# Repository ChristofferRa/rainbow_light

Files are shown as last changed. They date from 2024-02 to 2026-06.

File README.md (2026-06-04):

# Rainbow Lamp project

This is the code for my Wifi-connected rainbow-lamp project.  
The hardware is based on an ESP32-C3 super mini and a WS2812B-led strip in a custom designed 3d-printed enclosure in the form of a Rainbow and clouds.  
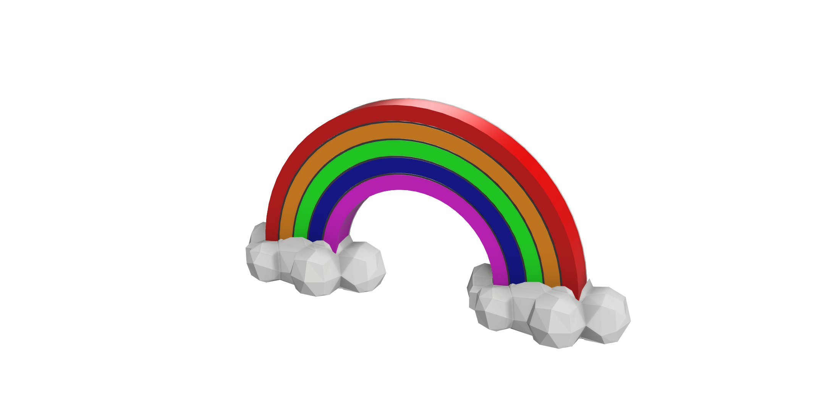
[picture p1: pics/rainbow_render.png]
Rainbow Render


## Features & Functionality
- **Home Assistant Native Integration**: Automatically discovered in Home Assistant using MQTT.
- **Captive Portal Setup**: Uses WiFiManager. If it can't connect to WiFi, it spins up an Access Point (`RainbowLamp_Setup`) where you can configure WiFi and MQTT credentials via your browser (times out after 5 minutes, after which it enters offline mode).
- **Animations**: Includes a few fun animations (Rainbow Chase, Pulse, Sparkle) selectable via Home Assistant. Animations automatically revert to the normal static rainbow after 5 minutes.
- **Auto-Brightness**: Adjusts brightness automatically using a photoresistor (LDR) and reports the ambient light level back to Home Assistant (0-100%).
- **OTA Updates**: Supports over-the-air firmware flashing via PlatformIO.
- **Hardware Watchdog**: Built-in ESP32 task watchdog ensures the lamp automatically recovers if an animation loop ever stalls (automatically bypassed during OTA updates to prevent reboots during flashing).

## 3D-printed parts
stl:s for 3D-printed parts can be found at [Printables](https://www.printables.com/@christofferra_319142/models)

## Hardware
1 x [ESP32 C3 Super Mini](https://vi.aliexpress.com/item/1005005877531694.html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)  
1 x [Female USB-C break out board](https://vi.aliexpress.com/item/1005001337982060.html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)  
1 x [1m WS2812B, 144led/m IP30](https://vi.aliexpress.com/item/32682015405.html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)  
1 x [GL-5516 LDR Photo resistor](https://vi.aliexpress.com/item/32833626809.html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)  
1 x 25v 1000microF Electrolytic capacitor  
1 x 330 ohm resistor  
1 x 10kohm resistor  
6 x M2 * L5 * D3.5 brass inserts  
10 x M2 * L8  

### Pin Mapping
- **WS2812B LED Strip**: GPIO 4
- **LDR Photoresistor (Analog)**: GPIO 0

### Circuit diagram
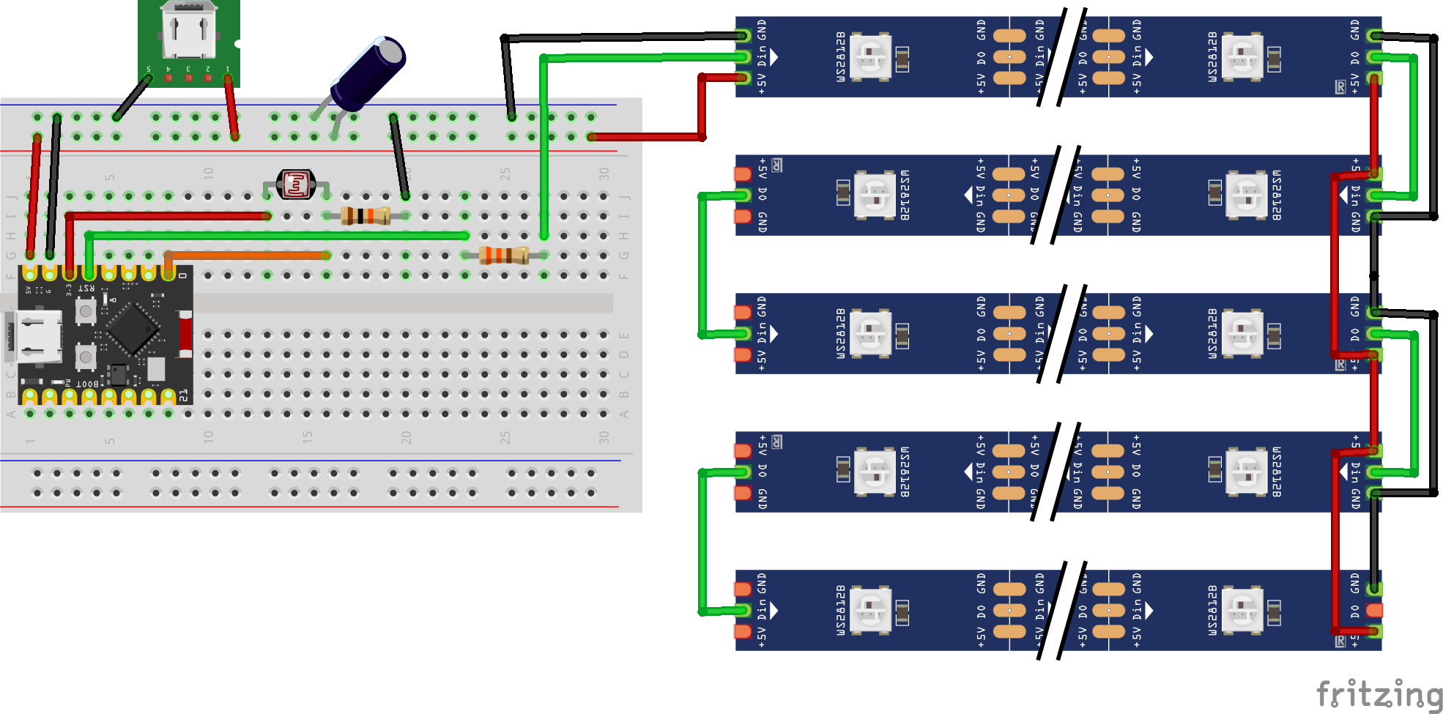
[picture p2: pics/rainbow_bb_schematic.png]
Breadboard

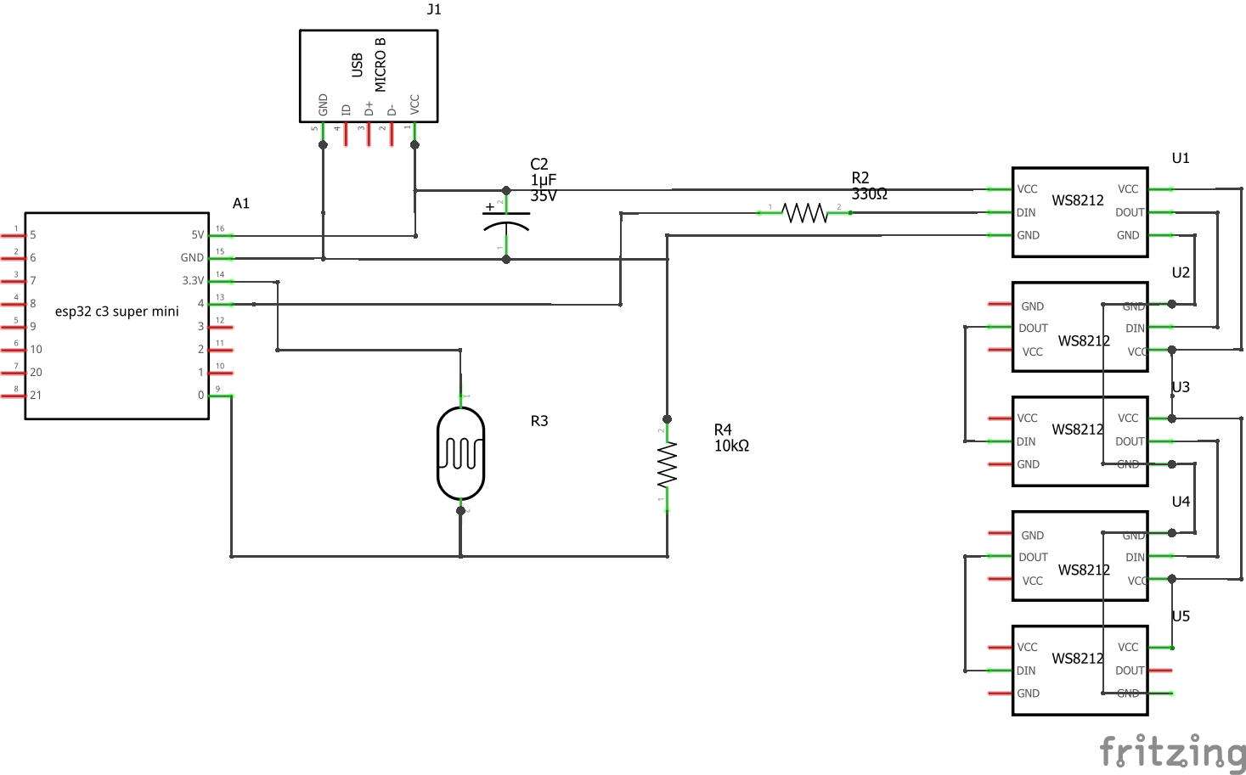
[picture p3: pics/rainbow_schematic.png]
Schematic


## Setup and Installation

### Prerequisites
- PlatformIO IDE installed in VS Code or CLI.
- ESP32 board definitions and libraries (handled automatically by PlatformIO on build).

### Configuration
1. Clone or copy the project files to your working directory.
2. Ensure you have the `platformio.ini` configured correctly for the `lolin_c3_mini` environment.
3. The OTA password can be defined in `platformio.ini` with `-D OTA_PASSWORD='"your_password"'`.

### Initial Flash
For the first setup, connect the ESP32-C3 Super Mini to your computer via USB:

1. Build and upload the project using PlatformIO via serial port.
2. Open the Serial Monitor at `115200` baud.

### WiFi and MQTT Provisioning
1. When the device boots for the first time, it creates a wireless access point named `RainbowLamp_Setup`.
2. Connect to the access point with a smartphone or computer.
3. A captive portal page should open automatically. If not, navigate to `192.168.4.1` in your browser.
4. Input your WiFi credentials along with your MQTT Server IP, username, and password.
5. The device will save these settings, connect to your WiFi, and start publishing to MQTT.

## Home Assistant Integration
Once connected to your MQTT broker, the device uses the Home Assistant MQTT discovery protocol to automatically register. It exposes the following entities under the device **Rainbow Light**:

- **switch.power**: Controls the power state of the LEDs.
- **number.brightness**: Controls the brightness level of the LEDs (only effective when auto-brightness is off).
- **switch.auto_brightness**: Toggles the automatic brightness adjustment based on the ambient light sensor.
- **sensor.light_level**: Current ambient light level mapped from 0-100%.
- **sensor.signal_strength**: Current WiFi RSSI in dBm.
- **select.animation**: Select an animation to play for 5 minutes (`Normal`, `Rainbow Chase`, `Pulse`, `Sparkle`).

## Over-the-Air (OTA) Updates
Once configured and connected to your network, you can upload new code over-the-air using PlatformIO:

```bash
pio run -t upload --upload-port rainbow_lamp.local
```
*(You can also configure this upload port in platformio.ini)*

The hardware watchdog task is automatically bypassed during OTA updates to prevent any reboots during the flash process.

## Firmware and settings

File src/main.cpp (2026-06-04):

// ESP32-C3 Rainbow Lamp Main Control Code
// Configured with WiFiManager captive portal (5-minute timeout), ArduinoOTA, Hardware Watchdog,
// and Home Assistant integration (discrete entities). Removed uptime sensor.
#include <Arduino.h>
#include <Wire.h>
#include <WiFi.h>
#include <WiFiManager.h>
#include <ArduinoOTA.h>
#include <ArduinoHA.h>
#include <esp_task_wdt.h>
#include <Adafruit_NeoPixel.h>
#include "SettingsManager.h"

// Watchdog timeout in seconds
#define WDT_TIMEOUT 10

//***************************
//***        WiFi         ***
//***************************
WiFiClient espClient;

//***************************
//***   Home Assistant    ***
//***************************
HADevice device;
// Using single client class for device-wide subscription list
HAMqtt mqtt(espClient, device);

HASwitch powerSwitch("rainbow_power");
HANumber brightnessNumber("rainbow_brightness");
HASwitch autoBrightnessSwitch("rainbow_auto_brightness");
HASensorNumber lightSensor("rainbow_light_sensor", HASensorNumber::PrecisionP1);
HASensorNumber rssiSensor("rainbow_rssi", HASensorNumber::PrecisionP0);
HASelect animationSelect("rainbow_animation");

//***************************
//***      Sensors        ***
//***************************
const int light_sensor_pin = 0; // photoresistor sensor pin

//***************************
//***       LED-Strip     ***
//***************************
#define WS2812B_PIN 4
const int Num_Rings = 5;
const int Pixels_In_Ring[] = {37, 33, 28, 25, 24};
const int Num_Pixels = 37 + 33 + 28 + 25 + 24;
Adafruit_NeoPixel WS2812B(Num_Pixels, WS2812B_PIN, NEO_GRB + NEO_KHZ800);

struct rgb_colors {
  int r, g, b;
};
rgb_colors ring_color[Num_Rings];

// State
bool light_on = true;
int brightness_level = 15;
bool auto_brightness = true;
const int max_brightness_allowed = 50;
const int min_brightness_allowed = 1;

enum AnimationMode {
  ANIM_NORMAL = 0,
  ANIM_RAINBOW_CHASE,
  ANIM_PULSE,
  ANIM_SPARKLE
};
AnimationMode currentAnimation = ANIM_NORMAL;
unsigned long animationStartTime = 0;
const unsigned long ANIMATION_TIMEOUT = 5 * 60 * 1000; // 5 minutes

// Forward declarations
void light_rainbow();
void light_off();
void update_leds();
void run_animation();

// HA Callbacks
void onPowerCommand(bool state, HASwitch *sender) {
  light_on = state;
  sender->setState(state); // Report back
  if (!light_on) {
    light_off();
  } else {
    update_leds();
  }
}

void onBrightnessCommand(HANumeric number, HANumber *sender) {
  if (!auto_brightness) {
    brightness_level = number.toInt8();
    sender->setState(number); // Report back
    if (light_on)
      update_leds();
  }
}

void onAutoBrightnessCommand(bool state, HASwitch *sender) {
  auto_brightness = state;
  sender->setState(state);
  if (!auto_brightness) {
    // Report current brightness to the slider
    brightnessNumber.setCurrentState((int32_t)brightness_level);
  }
}

void onAnimationCommand(int8_t index, HASelect *sender) {
  currentAnimation = (AnimationMode)index;
  sender->setState(index);
  animationStartTime = millis();
  if (light_on) {
    if (currentAnimation == ANIM_NORMAL) {
      light_rainbow();
    }
  }
}

void setup_ha() {
  byte mac[6];
  WiFi.macAddress(mac);
  device.setUniqueId(mac, sizeof(mac));
  device.setName("Rainbow Light");
  device.setSoftwareVersion("2.0.0");
  device.setManufacturer("Rapp Industries");
  device.setModel("Rainbow 1");

  powerSwitch.setName("Power");
  powerSwitch.setIcon("mdi:power");
  powerSwitch.onCommand(onPowerCommand);

  brightnessNumber.setName("Brightness");
  brightnessNumber.setIcon("mdi:brightness-6");
  brightnessNumber.setMin(min_brightness_allowed);
  brightnessNumber.setMax(max_brightness_allowed);
  brightnessNumber.onCommand(onBrightnessCommand);

  autoBrightnessSwitch.setName("Auto Brightness");
  autoBrightnessSwitch.setIcon("mdi:brightness-auto");
  autoBrightnessSwitch.onCommand(onAutoBrightnessCommand);

  lightSensor.setName("Light Level");
  lightSensor.setUnitOfMeasurement("%");
  // Removed setDeviceClass("illuminance") because % unit of measurement is not
  // supported by the illuminance device class in HA.

  rssiSensor.setName("Signal Strength");
  rssiSensor.setUnitOfMeasurement("dBm");
  rssiSensor.setDeviceClass("signal_strength");

  animationSelect.setName("Animation");
  animationSelect.setOptions("Normal;Rainbow Chase;Pulse;Sparkle");
  animationSelect.onCommand(onAnimationCommand);

  mqtt.setBufferSize(1024);
  mqtt.begin(Settings.mqttServer.c_str(), Settings.mqttUser.c_str(),
             Settings.mqttPass.c_str());
}

void get_light_conditions() {
  int max_light_conditions = 4095;
  int min_light_conditions = 0;
  double k = ((double)(max_brightness_allowed - min_brightness_allowed)) /
             (max_light_conditions - min_light_conditions);

  double adc_val = 0;
  int nrSamples = 5;
  for (int i = 0; i < nrSamples; i++) {
    adc_val += analogRead(light_sensor_pin);
    delay(50);
  }
  adc_val /= nrSamples;

  if (auto_brightness) {
    brightness_level =
        k * (adc_val - min_light_conditions) + min_brightness_allowed;
    brightnessNumber.setCurrentState((int32_t)brightness_level);
    if (light_on && currentAnimation == ANIM_NORMAL) {
      WS2812B.setBrightness(brightness_level);
      WS2812B.show();
    }
  }

  // Publish sensor % (0-100)
  float percent = (adc_val / 4095.0) * 100.0;
  lightSensor.setValue(percent);
}

void light_rainbow() {
  int pixel_to_light;
  int pixels_in_previous_rings;
  for (int j = 0; j < Num_Rings; j++) {
    pixels_in_previous_rings = 0;
    for (int k = 0; k < j; k++) {
      pixels_in_previous_rings += Pixels_In_Ring[k];
    }
    for (int p = 0; p < Pixels_In_Ring[j]; p++) {
      pixel_to_light = p + pixels_in_previous_rings;
      WS2812B.setPixelColor(
          pixel_to_light,
          WS2812B.Color(ring_color[j].r, ring_color[j].g, ring_color[j].b));
    }
  }
  WS2812B.setBrightness(brightness_level);
  WS2812B.show();
}

void light_off() {
  WS2812B.clear();
  WS2812B.show();
}

void update_leds() {
  if (currentAnimation == ANIM_NORMAL) {
    light_rainbow();
  }
}

// Simple animations
void anim_rainbow_chase() {
  static uint16_t j = 0;
  for (int i = 0; i < WS2812B.numPixels(); i++) {
    esp_task_wdt_reset(); // Feed WDT
    WS2812B.setPixelColor(i, WS2812B.gamma32(WS2812B.ColorHSV(
                                 (i * 65536L / WS2812B.numPixels()) + j)));
  }
  WS2812B.setBrightness(brightness_level);
  WS2812B.show();
  j += 256;
}

void anim_pulse() {
  static int p = 0;
  static int dir = 1;

  // Draw base rainbow
  light_rainbow();

  // Adjust global brightness based on pulse
  float factor = (float)p / 100.0;
  int current_bright = brightness_level * factor;
  WS2812B.setBrightness(max(1, current_bright));
  WS2812B.show();

  p += dir * 2;
  if (p >= 100)
    dir = -1;
  if (p <= 10)
    dir = 1;
}

void anim_sparkle() {
  light_rainbow();
  int randomPixel = random(WS2812B.numPixels());
  WS2812B.setPixelColor(randomPixel, WS2812B.Color(255, 255, 255));
  WS2812B.show();
  delay(50);
}

void run_animation() {
  if (currentAnimation == ANIM_NORMAL)
    return;

  if (millis() - animationStartTime > ANIMATION_TIMEOUT) {
    currentAnimation = ANIM_NORMAL;
    animationSelect.setState(ANIM_NORMAL);
    light_rainbow();
    return;
  }

  switch (currentAnimation) {
  case ANIM_RAINBOW_CHASE:
    anim_rainbow_chase();
    delay(10);
    break;
  case ANIM_PULSE:
    anim_pulse();
    delay(20);
    break;
  case ANIM_SPARKLE:
    anim_sparkle();
    break;
  default:
    break;
  }
}

void setup() {
  Serial.begin(115200);
  Settings.init();

  ring_color[0] = {255, 0, 0};   // ring 1, red
  ring_color[1] = {230, 115, 0}; // ring 2, orange
  ring_color[2] = {0, 255, 0};   // ring 3, green
  ring_color[3] = {0, 0, 255};   // ring 4, blue
  ring_color[4] = {179, 0, 179}; // ring 5, violet

  WS2812B.begin();
  light_off();

  WiFi.mode(WIFI_STA);
  WiFi.setTxPower(WIFI_POWER_8_5dBm); // Workaround for getting wifi working
                                      // stably on ESP32-C3

  WiFiManager wm;
  WiFiManagerParameter custom_mqtt_server("server", "MQTT Server",
                                          Settings.mqttServer.c_str(), 40);
  WiFiManagerParameter custom_mqtt_user("user", "MQTT Username",
                                        Settings.mqttUser.c_str(), 40);
  WiFiManagerParameter custom_mqtt_pass("pass", "MQTT Password",
                                        Settings.mqttPass.c_str(), 40,
                                        "type=\"password\"");

  wm.addParameter(&custom_mqtt_server);
  wm.addParameter(&custom_mqtt_user);
  wm.addParameter(&custom_mqtt_pass);

  // Boot animation
  WS2812B.setPixelColor(0, WS2812B.Color(255, 115, 0));
  WS2812B.setBrightness(15);
  WS2812B.show();

  // Force config portal if MQTT is not configured
  if (Settings.mqttServer == "") {
    wm.resetSettings();
  }

  wm.setConfigPortalTimeout(300); // 5 minute timeout for the portal

  if (!wm.autoConnect("RainbowLamp_Setup")) {
    Serial.println(
        "Failed to connect and hit timeout. Continuing without WiFi.");
  } else {
    Serial.println("Connected to WiFi!");
    // Only save credentials if we actually connected via the portal or
    // successfully booted
    Settings.saveMqttCredentials(custom_mqtt_server.getValue(),
                                 custom_mqtt_user.getValue(),
                                 custom_mqtt_pass.getValue());
  }

  // Hostname
  String hostname = "RainbowLamp-" + WiFi.macAddress();
  hostname.replace(":", "");
  WiFi.setHostname(hostname.c_str());

  // OTA Setup
  ArduinoOTA.setHostname("rainbow_lamp");
#ifdef OTA_PASSWORD
  ArduinoOTA.setPassword(OTA_PASSWORD);
#endif
  ArduinoOTA.onStart([]() {
    // Remove loopTask from the watchdog during OTA to prevent reboots during
    // flashing
    esp_task_wdt_delete(NULL);
  });
  ArduinoOTA.begin();

  setup_ha();

  // Get initial light level and adjust brightness immediately
  get_light_conditions();

  // Init state
  powerSwitch.setCurrentState(true);
  autoBrightnessSwitch.setCurrentState(true);
  brightnessNumber.setCurrentState((int32_t)brightness_level);
  animationSelect.setCurrentState(ANIM_NORMAL);

  light_rainbow();

  // Initialize Watchdog after WiFi is connected to avoid WDT triggers during
  // captive portal
  esp_task_wdt_init(WDT_TIMEOUT, true);
  esp_task_wdt_add(NULL);
}

void loop() {
  esp_task_wdt_reset(); // Feed WDT
  if (WiFi.status() == WL_CONNECTED) {
    ArduinoOTA.handle();
    mqtt.loop();
  }

  static unsigned long lastLightUpdate = 0;
  if (lastLightUpdate == 0 || millis() - lastLightUpdate > 60000) {
    lastLightUpdate = millis();
    get_light_conditions();
  }

  static unsigned long lastDiagUpdate = 0;
  if (lastDiagUpdate == 0 || millis() - lastDiagUpdate > 60000) {
    lastDiagUpdate = millis();
    if (WiFi.status() == WL_CONNECTED) {
      rssiSensor.setValue(WiFi.RSSI());
    }
  }

  if (light_on) {
    run_animation();
  }
}

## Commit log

2024-02-19 added readme
    [rainbow.fzz]
2024-02-19 changed startup animation and fixed some bugs
    [main.cpp]
2026-06-04 Refactor: Add SettingsManager, remove uptime sensor, and fix OTA watchdog reset
    [main.cpp]
